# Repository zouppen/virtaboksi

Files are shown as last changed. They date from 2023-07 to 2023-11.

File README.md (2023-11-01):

# Virtaboksi

Virtaboksi is a multi-purpose 3-channel common-earth power switch,
rating 12–48 VDC, 20 A. It has multiple operating modes:

* **Home/away switch** supporting three individual groups and is optimized
  for solar energy off-grid applications.

* **Water pump controller** with pressure sensor input and control for
  combined submersible and pressure pump system. Additionally, a
  throw-over switching capability to drop loads while pumping.

* Generic **Modbus RTU server** (slave) with 3 solid-state "coils", 3 digital
  outputs, and 4 digital inputs.

3D model

In the picture above the Powerpole connector colors are incorrect. Red
is used for inputs and black for outputs. In a real product, the three
groups have different colors: red, yellow and blue.

## Design principles

* **Flexible voltage** options; 10–34 V input on first group, 10–60 V on
  second and third group.
* **High current** support. With passive cooling, 20 A loads can be
  controlled. MOSFETs are capable of switching over 100 A continuous
  current in case where cooling and PCB traces are reinforced.
* **Small** size: Thanks to transistor control, the size is way smaller than for
  three contactors of similar rating.
* **Low losses**: Internal resistance <10mΩ.
* **Rugged**: All digital I/O ports are short-circuit, reverse voltage and
  surge protected.
* **Power saving**: When loads are off, the power consumption is minimal,
  less than 5mW, allowing it to be left powered on over dark winters.
* **Hacker friendly**: You can create your own firmware for the STM8
  microcontroller, allowing real-time and stand-alone control of your
  loads and connectivity to other peripherals up to **1 km** distance
  over RS-485.

## Operating modes

### Home/away mode

Status: 💚 **Functional**

This unit provides *priority* output on OUT1 when the switch is in
either *home* or *away* position. *Home* controls OUT2 and OUT3 groups
and can be used to control two separate voltages as long as they have
a common ground.

An example use case is a solar off-grid system with two 12V batteries
in series providing 24 volts, plus 12 volts generated from 24V using a
step-down DC converter. DC converter is not included in the package.

In that case this switch can be used to turn the loads partially while
being away, such as keeping refrigerator running but turning off
lights while not present. When using a DC converter, its input is connected
OUT1 its output (12V) to IN3.

Maximum voltage in IN1 is 34 VDC. The limitation comes from the
internal power supply. In case you want to use higher voltages in IN1,
cut the trace F1 on the bottom of this board and power the system
directly from a regulated 3.3 VDC supply via the terminals.

IN2 and IN3 are rated for 60 volts maximum, making it possible to
control 48V nominal voltage loads. Minimum voltage for all groups is
about 10 volts. Under 10 volts, MOSFET control becomes unreliable.

#### How to connect

In home/away mode, when I1 is shorted to the ground, the oprating mode
is *away*. When I2 is shorted, the mode is *home*. If both connectors
are open, operating mode is *off*.

Optionally, LED anodes can be connected directly to O1 and O2. They
represent home and away operating modes, in that order. There is a
current limiter controllable by R1 to limit the maximum current of
O1...O3 to about 15 mA by default, so series resistors are not needed.

If your solar controller has a low battery condition relay, it can be
connected to I3. When the input is high, the system is forced to off mode,
ignoring the state of home/away switch.

I4 is not used in this mode.

### Water pump controller mode

Status: 🔬 **Hardware OK**

Hardware is capable, but no firmware support yet.

### Modbus RTU server mode

Status: 🔬 **Hardware OK**

RS-485 hardware is tested and some firmware tests performed, but no
Modbus implementation exists yet.

## Building firmware

To build firmware, you need CMake and sdcc. The preparations are very
standard CMake stuff. In `firmware` subdirectory, run:

```sh
mkdir build
cd build
cmake ..
```

And then, `make` compiles it. Alternatively, `make upload` to compile
and flash.

## License

The firmware is free software: you can redistribute it and/or modify
it under the terms of the GNU Affero General Public License as
published by the Free Software Foundation, either version 3 of the
License, or (at your option) any later version.

The hardware is provided as source-available: The schematics and PCB
layout are provided for reference only. The files can be freely
distributed without limitations but no derivative works are allowed
without a permission from the copyright holders.

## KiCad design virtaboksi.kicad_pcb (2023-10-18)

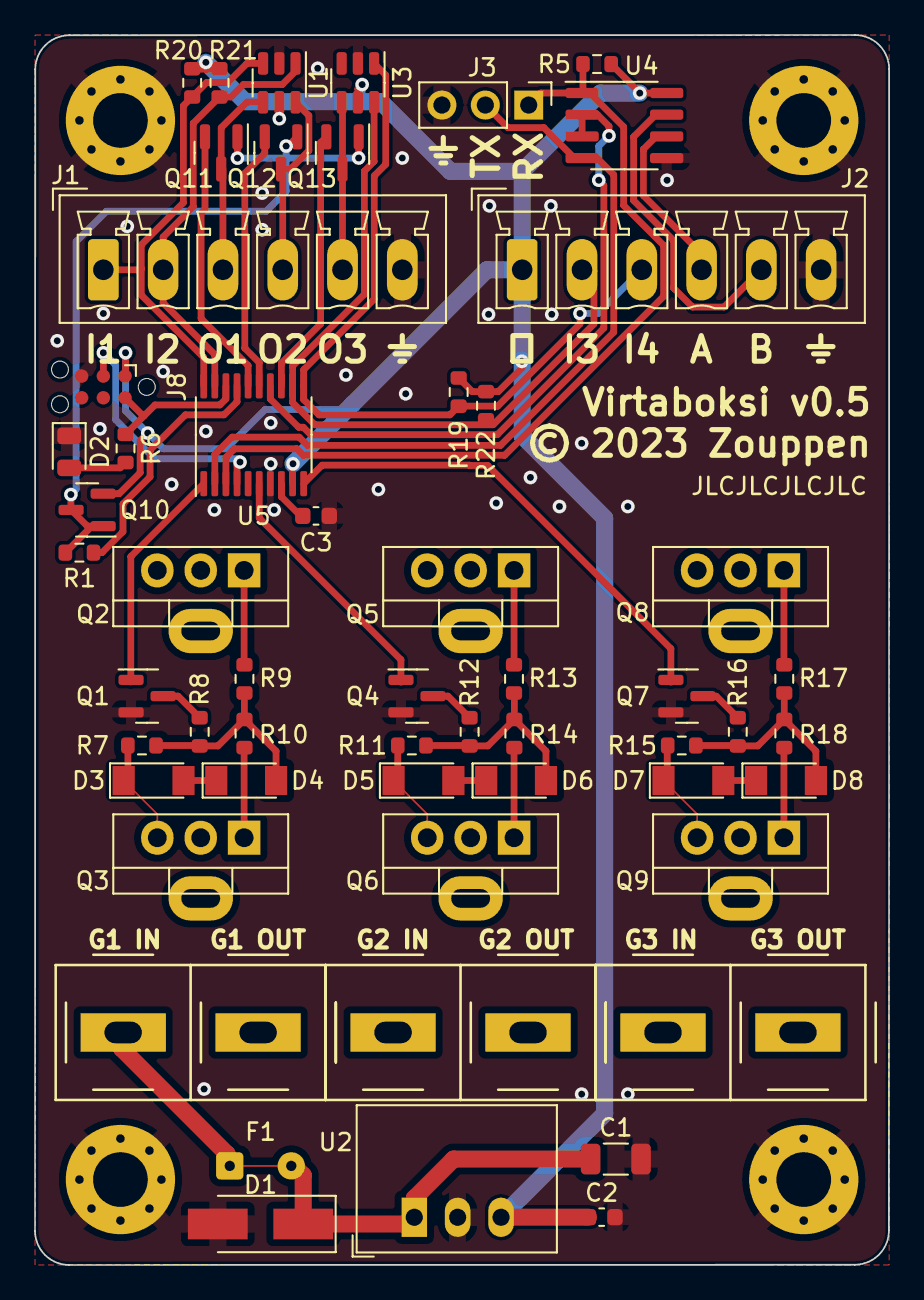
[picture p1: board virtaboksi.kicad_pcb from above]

Board: 2 copper layers, 50.0 x 72.0 mm, 66 parts (0 on the bottom side), 48 nets.

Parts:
C1: 10u; C_1206_3216Metric
C2: 22u; C_0603_1608Metric
C3: 1u; C_0603_1608Metric
D1: SMAJ33A; D_SMA_Handsoldering
D2: LED; LED_0805_2012Metric
D3, D4, D5, D6, D7, D8: ZMM5V6-M; D_MiniMELF
F1: Fuse; Fuse-kindof_1x02_P3.6mm_D0.4mm_OD1mm
H1, H2, H3, H4: MountingHole_Pad; MountingHole_3.2mm_M3_Pad_Via
HS1, HS2, HS3, HS4, HS5, HS6: Heatsink; Heatsink_AAVID_576802B03900G-nocourt
J1: Panel_01x06; PhoenixContact_MCV_1,5_6-G-3.5_1x06_P3.50mm_Vertical
J2: External_01x06; PhoenixContact_MCV_1,5_6-G-3.5_1x06_P3.50mm_Vertical
J3: Optional_01x03; PinHeader_1x03_P2.54mm_Vertical
J5, J6, J7: Powerpole 01x02; 45A-VERT-PAIR
J8: TagConnect_TC2030-NL; Tag-Connect_TC2030-IDC-NL_2x03_P1.27mm_Vertical
Q1, Q4, Q7: 2N7002; SOT-23
Q2, Q3, Q5, Q6, Q8, Q9: IRF4905; TO-220-3_Vertical
Q10, Q11, Q12, Q13: MMBT3906; SOT-23
R1, R6: 220; R_0603_1608Metric
R5: 20k; R_0603_1608Metric
R7, R11, R15: 68k; R_0603_1608Metric
R8, R12, R16: 13k; R_0603_1608Metric
R9, R10, R13, R14, R17, R18: 10; R_0603_1608Metric
R19, R20, R21, R22: 5k; R_0603_1608Metric
U1, U3: SRV05-4; SOT-23-6
U2: AMSRI-783.3-NZ; Converter_DCDC_RECOM_R-78E-0.5_THT
U4: SP3485EN; SOIC-8_3.9x4.9mm_P1.27mm
U5: STM8S003F3P; TSSOP-20_4.4x6.5mm_P0.65mm

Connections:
+3.3V: C2.1, J2.1, J8.1 (VCC), Q10.2 (E), R5.1, R19.1, R20.1, R21.1, R22.1, U1.5 (VP), U2.3 (OUT), U3.5 (VP), U4.8 (VCC), U5.9 (VDD)
/GROUP1 CTRL: Q1.1 (G), U5.1 (PD4)
/GROUP1 IN: D3.1 (K), F1.1, J7.2, Q2.3 (S), Q3.3 (S), R7.1
/GROUP1 OUT: HS1.1, HS2.1, J7.1, Q2.2 (D), Q3.2 (D)
/GROUP2 CTRL: Q4.1 (G), U5.6 (PA2)
/GROUP2 IN: D5.1 (K), J6.2, Q5.3 (S), Q6.3 (S), R11.1
/GROUP2 OUT: HS3.1, HS4.1, J6.1, Q5.2 (D), Q6.2 (D)
/GROUP3 CTRL: Q7.1 (G), U5.10 (PA3)
/GROUP3 IN: D7.1 (K), J5.2, Q8.3 (S), Q9.3 (S), R15.1
/GROUP3 OUT: HS5.1, HS6.1, J5.1, Q8.2 (D), Q9.2 (D)
/IN1: J1.1, R20.2, U1.3 (IO2), U5.20 (PD3)
/IN2: J1.2, R21.2, U1.1 (IO1), U5.19 (PD2)
/IN3: J2.2, R22.2, U3.6 (IO4), U5.12 (PB4)
/IN4: J2.3, R19.2, U3.1 (IO1), U5.11 (PB5)
/IREF: Q10.1 (B), Q10.3 (C), Q11.1 (B), Q12.1 (B), Q13.1 (B), R1.1
/IREF_EN: R1.2, U5.17 (PC7)
/O1: J1.3, Q11.3 (C), U1.4 (IO3)
/O1uC: Q11.2 (E), U5.16 (PC6)
/O2: J1.4, Q12.3 (C), U1.6 (IO4)
/O2uC: Q12.2 (E), U5.15 (PC5)
/O3: J1.5, Q13.3 (C), U3.4 (IO3)
/O3uC: Q13.2 (E), U5.13 (PC3)
/PWR1: C1.1, D1.1 (A1), F1.2, U2.1 (IN)
/RESET: J8.3 (~RESET), U5.4 (NRST)
/RX: J3.1, R5.2, U4.1 (RO), U5.3 (PD6)
/SWIM: J8.2 (SWDIO), R6.2, U5.18 (PD1)
/TX: J3.2, U4.4 (DI), U5.2 (PD5)
/TX_EN: U4.2 (~RE), U4.3 (DE), U5.14 (PC4)
/mosfet_switch1/DRIVE: D4.2 (A), R7.2, R8.1, R9.1, R10.1
/mosfet_switch1/DRIVE_A: Q2.1 (G), R9.2
/mosfet_switch1/DRIVE_B: Q3.1 (G), R10.2
/mosfet_switch2/DRIVE: D6.2 (A), R11.2, R12.1, R13.1, R14.1
/mosfet_switch2/DRIVE_A: Q5.1 (G), R13.2
/mosfet_switch2/DRIVE_B: Q6.1 (G), R14.2
/mosfet_switch3/DRIVE: D8.2 (A), R15.2, R16.1, R17.1, R18.1
/mosfet_switch3/DRIVE_A: Q8.1 (G), R17.2
/mosfet_switch3/DRIVE_B: Q9.1 (G), R18.2
A: J2.4, U4.6 (A)
B: J2.5, U4.7 (B)
GND: C1.2, C2.2, C3.2, D1.2 (A2), D2.1 (K), H1.1, H2.1, H3.1, H4.1, J1.6, J2.6, J3.3, J8.5 (GND), Q1.2 (S), Q4.2 (S), Q7.2 (S), U1.2 (VN), U2.2 (GND), U3.2 (VN), U4.5 (GND), U5.7 (VSS)
unnamed: C3.1, U5.8 (VCAP)
unnamed: D2.2 (A), R6.1
unnamed: D3.2 (A), D4.1 (K)
unnamed: D5.2 (A), D6.1 (K)
unnamed: D7.2 (A), D8.1 (K)
unnamed: Q1.3 (D), R8.2
unnamed: Q4.3 (D), R12.2
unnamed: Q7.3 (D), R16.2

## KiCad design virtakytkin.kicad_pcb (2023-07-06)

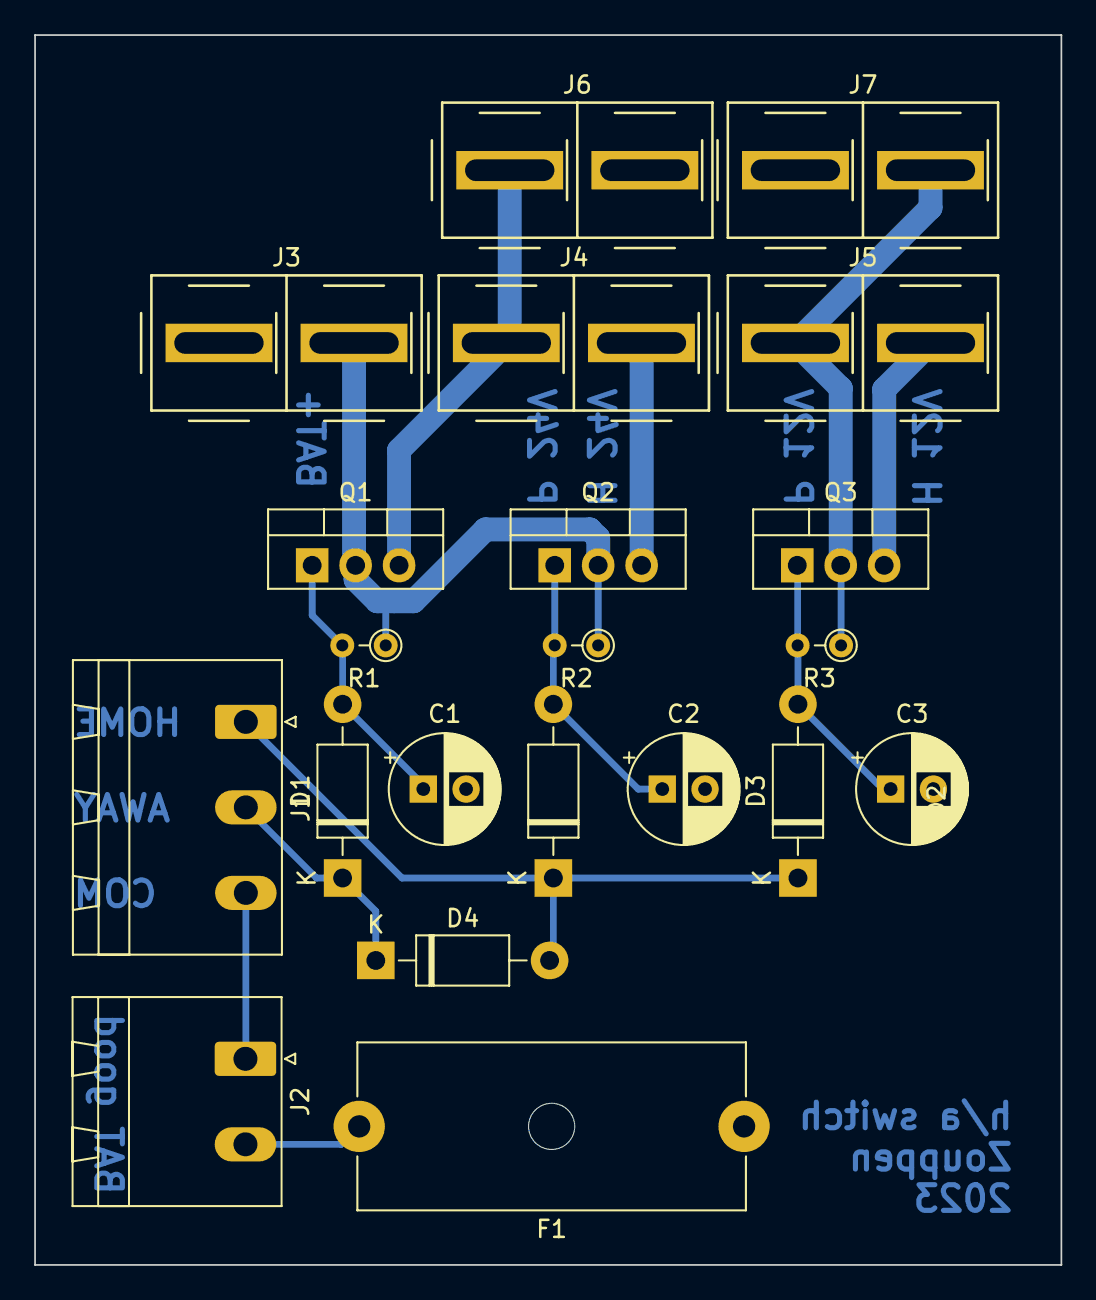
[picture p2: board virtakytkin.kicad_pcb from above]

Board: 2 copper layers, 60.0 x 71.9 mm, 21 parts (0 on the bottom side), 13 nets.

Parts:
C1, C2, C3: C_Polarized; CP_Radial_D6.3mm_P2.50mm
D1, D2, D3, D4: 1N4001; D_DO-41_SOD81_P10.16mm_Horizontal
F1: Fuse; Fuseholder_Cylinder-5x20mm_Schurter_0031_8201_Horizontal_Op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
J1: Conn_01x03_Female; PhoenixContact_MSTBA_2,5_3-G_1x03_P5.00mm_Horizontal
J2: Conn_01x02_Female; PhoenixContact_MSTBA_2,5_2-G_1x02_P5.00mm_Horizontal
J3, J4, J5, J6, J7: Conn_01x02_Female; 45A-VERT-PAIR
Q1, Q2, Q3: IRF9540N; TO-220-3_Vertical
R1, R2, R3: 100k; R_Axial_DIN0204_L3.6mm_D1.6mm_P2.54mm_Vertical

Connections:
+BATT: J3.2, Q1.2 (D), Q2.2 (D), R1.1, R2.1
/AWAY: D1.1 (K), D4.1 (K), J1.2
/BAT GOOD: J1.3, J2.1
/HOME: D2.1 (K), D3.1 (K), D4.2 (A), J1.1
/HOME 12V: J5.2, Q3.3 (S)
/HOME 24V: J4.2, Q2.3 (S)
/PRI 12V: J5.1, J7.2, Q3.2 (D), R3.1
/PRI 24V: J4.1, J6.1, Q1.3 (S)
GND: C1.2, C2.2, C3.2, F1.1, J3.1, J6.2, J7.1
unnamed: C1.1, D1.2 (A), Q1.1 (G), R1.2
unnamed: C2.1, D2.2 (A), Q2.1 (G), R2.2
unnamed: C3.1, D3.2 (A), Q3.1 (G), R3.2
unnamed: F1.2, J2.2

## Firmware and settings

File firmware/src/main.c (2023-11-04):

/* Firmware for Virtaboksi v0.4 and above */
#include <stm8.h>
#include <string.h>
#include "board.h"
#include "iref.h"
#include "util.h"
#include "serial.h"
#include "timers.h"
#include "settings.h"

#define HALT_ENABLED

// On bootup, have a small pause after bootup before switching loads,
// to avoid oscillation in case of a boot loop.
static uint16_t ctrl_debounce = STARTUP_DEBOUNCE_TICKS;

// In case excessive flipflopping, turn all outputs off since it might
// be an indicator of a hardware error.
static uint16_t ctrl_panic = PANIC_OFF_TICKS;

// A global flag for carrying state from ISR to main loop
static volatile bool timers_running = true;

static void controlled_halt(void);
static void update_outputs_IM(bool const panic);
static void debounce_arm_IM(void);
static bool debounce_tick_IM(void);
static void setup_IM(void);
static void loop(void);

// Halts CPU. This must be called outside of interrupt handlers but
// interrupts disabled. Like wfi(), enables interrupts on return.
static void controlled_halt(void)
{
	// "Unreal mode" for serial traffic. Enable interrupt for the
	// serial pin and it magically wakes up after serial activity,
	// although this shouldn't be possible according to STM8S data
	// sheet (rx can't emit an interrupt while in HALT mode.
	REG_HIGH(CR2, PIN_RX);

	// Turn off the running indicator
	LOW(PIN_LED_PCB);

	// We may wake up because of start bit on UART line, meaning
	// the first byte hasn't been yet received. Ensuring that
	// we'll stay awake until the end of first byte at minimum.
	timers_stay_awake_IM(MINIMUM_WAKEUP_TICKS);
	timers_running = true;

	// Put IREF to powersave if no LEDs are lit
	iref_maybe_off_IM();

	halt();

	// WAKE UP!! Rise and shine! Interrupts are automatically
	// enabled on wake-up, so suppressing them again. In case of
	// serial traffic, int_on_portd() has been already called
	// before getting here because it's impossible to wake up
	// without going to interrupt handlers.
	__critical {
		// Suppress future spurious calls to int_on_portd()
		REG_LOW(CR2, PIN_RX);

		// Put IREF on while we stay awake
		iref_on_IM();
	}
}

static void update_outputs_IM(bool const panic)
{
	bool const sw_away = !READ(PIN_IN1);
	bool const sw_home = !READ(PIN_IN2);
	bool const bat_good = READ(PIN_IN3);
	bool const sw_main = sw_home || sw_away;

	if (panic || !bat_good || !sw_main) {
		// BAT bad or OFF state: all outputs off
		LOW(PIN_GROUP1);
		LOW(PIN_GROUP2);
		LOW(PIN_GROUP3);
		// Indicator LEDs
		LOW(PIN_OUT1);
		LOW(PIN_OUT2);
	} else if (sw_home) {
		// Home: All outputs on
		HIGH(PIN_GROUP1);
		HIGH(PIN_GROUP2);
		HIGH(PIN_GROUP3);
		// Indicator LEDs
		LOW(PIN_OUT1);
		HIGH(PIN_OUT2);
	} else {
		// Away: PRI on
		HIGH(PIN_GROUP1);
		LOW(PIN_GROUP2);
		LOW(PIN_GROUP3);
		// Indicator LEDs
	        HIGH(PIN_OUT1);
		LOW(PIN_OUT2);
	}
}

static void debounce_arm_IM(void)
{
	ctrl_debounce = DEBOUNCE_TICKS;
}

static bool debounce_tick_IM(void)
{
	if (ctrl_debounce) {
		if (--ctrl_debounce) {
			// Still running
			if (ctrl_panic && !--ctrl_panic) {
				// Running for too long
				update_outputs_IM(true);
			}
			return true;
		}
		// Reached zero
		ctrl_panic = PANIC_OFF_TICKS;
		update_outputs_IM(false);
	}
	return false;
}

void int_on_portb(void) __interrupt(EXTI1_ISR)
{
	debounce_arm_IM();
}

void int_on_portc(void) __interrupt(EXTI2_ISR)
{
	debounce_arm_IM();
}

void int_on_portd(void) __interrupt(EXTI3_ISR)
{
	// OBS! When we wake up from serial activity, we get here once
	// and it's inevitable.
}

void run_every_1ms(void) __interrupt(TIM2_OVF_ISR)
{
	// Clear Timer 2 Status Register 1 Update Interrupt Flag (UIF)
	TIM2_SR1 &= ~TIM_SR1_UIF;

	// Blink the LED when in operation
	TOGGLE(PIN_LED_PCB);

	// Process ticks
	bool const debouncing = debounce_tick_IM();
	bool const ticking = timers_tick_IM();
	serial_tick_IM();

	// Update the global flag to indicate readiness for a sleep.
	timers_running = debouncing || ticking;
}

int main(void)
{
	// Configure device and enable interrupts.
	setup_IM();
	enable_interrupts();

	// Stay in light sleep to keep timers going. If nothing to
	// run, go to halt mode.
	while (true) {
		loop();

		// Block interrupts while whe figure out sleep method.
		disable_interrupts();

		// If there are still messages to process, go to loop.
		if (serial_has_message_IM()) {
			enable_interrupts();
			continue;
		}
#ifdef HALT_ENABLED
		if (!timers_running && !serial_is_transmitting()) {
			controlled_halt();
		} else {
			wfi();
		}
#else
		wfi();
#endif
		// Both controlled_halt() and wfi() implicitly enable
		// interrupts.
	}
}

static void setup_IM(void)
{
	// Setting clock speed
	stm8_configure_clock();

	settings_init();

	// As suggested in chapter 11.5 of RM0016, unused pins are set
	// to pull-up state. We make them all pull-up first, it's safe.
	PA_CR1 = 0xFF;
	PB_CR1 = 0xFF;
	PC_CR1 = 0xFF;
	PD_CR1 = 0xFF;
	PE_CR1 = 0xFF;
	PF_CR1 = 0xFF;

	// LED is push-pull output (CR1 already set)
	OUTPUT(PIN_LED_PCB);

	// Inputs have already discrete pull-up resistors, so we turn
	// their pull-up off (CR1) and enable interrupts (CR2).
	REG_LOW(CR1, PIN_IN1);
	REG_LOW(CR1, PIN_IN2);
	REG_LOW(CR1, PIN_IN3);
	REG_LOW(CR1, PIN_IN4);
	REG_HIGH(CR2, PIN_IN1);
	REG_HIGH(CR2, PIN_IN2);
	REG_HIGH(CR2, PIN_IN3);
	REG_HIGH(CR2, PIN_IN4);

	// Serial port has an external pull-up, too, disabling pull-up
	REG_LOW(CR1, PIN_RX);

	// MOSFET controls and LEDs are push-pull outputs
	// (CR1 already set)
	OUTPUT(PIN_GROUP1);
	OUTPUT(PIN_GROUP2);
	OUTPUT(PIN_GROUP3);
	OUTPUT(PIN_OUT1);
	OUTPUT(PIN_OUT2);
	OUTPUT(PIN_OUT3);

	// Must be on before LEDs are controlled
	BOARD_IREF_CONF;
	iref_on_IM();

	// Make interrupts trigger on both edges
	EXTI_CR1 = 0xff;

	// Timer prescale to 125 kHz
	TIM2_PSCR = TICK_PRESCALE;
	// Counter Auto-Reload Registers, the main tick timer
	TIM2_ARRH = TICK_USEC >> 8;
	TIM2_ARRL = TICK_USEC & 0xff;
	// Interrupt Enable Register, Update interrupt (UIE)
	TIM2_IER = TIM_IER_UIE;
	// Control Register 1, Counter ENable bit (CEN)
	TIM2_CR1 = TIM_CR1_CEN;

	serial_init();
}

// Run after waking up from the interrupts. Can be used to
// perform longer duration tasks. Interrupts are enabled.
static void loop(void)
{
	serial_buffer_t *const rx = serial_get_message();
	if (rx == NULL) return;

	if (rx->state == TEXT) {
		if (!strcmp(rx->data, "PAUSES")) {
			strcpy(serial_tx, "taukoja ei ole");
		} else {
			// We've got a line, let's convert it. This is a
			// little bit unsafe, but is a placeholder for the
			// real logic only.
			strcpy(serial_tx, "Saatiin: ");
			buflen_t const head = 9;
			for (buflen_t i=0; i<SERIAL_TX_LEN-head; i++) {
				char const c = rx->data[i];
				if (c == '\0') {
					serial_tx[head+i] = '\0';
					break;
				} else {
					serial_tx[head+i] = util_rot13(c);
				}
			}
		}
		serial_tx_line();
	} else {
		// We don't understand this message type (yet)
	}

	serial_free_message();
}

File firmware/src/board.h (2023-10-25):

#pragma once

#if defined BOARD_0_4
// Board version 0.4 configuration
#define PIN_IN1       PC,7
#define PIN_IN2       PC,6
#define PIN_IN3       PC,5
#define PIN_IN4       PC,4
#define PIN_GROUP1    PD,4
#define PIN_GROUP2    PA,3
#define PIN_GROUP3    PA,2
#define PIN_OUT1      PB,4
#define PIN_OUT2      PB,5
#define PIN_OUT3      PC,3
#define PIN_LED_PCB   PD,1
#define PIN_TX_EN     PD,2,3

// IREF is not present on this board
#define BOARD_IREF_CONF
#define BOARD_IREF_ON
#define BOARD_IREF_OFF

#elif defined BOARD_0_5
// Board version 0.5 configuration
#define PIN_IN1       PC,7
#define PIN_IN2       PC,4
#define PIN_IN3       PB,4
#define PIN_IN4       PB,5
#define PIN_GROUP1    PD,4
#define PIN_GROUP2    PA,2
#define PIN_GROUP3    PA,3
#define PIN_OUT1      PC,6
#define PIN_OUT2      PC,5
#define PIN_OUT3      PC,3
#define PIN_LED_PCB   PD,1
#define PIN_TX_EN     PD,2

// IREF is not present on this board
#define BOARD_IREF_CONF  OUTPUT(PD,3)
#define BOARD_IREF_ON    HIGH(PD,3)
#define BOARD_IREF_OFF   LOW(PD,3)

#else
#error Unknown board version.
#endif

// Constant pins for STM8S003
#define PIN_RX        PD,6

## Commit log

2023-07-06 Add current version of the project
    [virtakytkin.kicad_pcb, virtakytkin.kicad_sch]
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2023-07-06 Move powerpoles so that they are stackable
    [virtaboksi.kicad_pcb]
2023-07-06 Fine-tuning of the board
    [virtaboksi.kicad_pcb, virtaboksi.kicad_sch]
2023-07-06 Finetuning layout & adding TVS diode
    [virtaboksi.kicad_pcb, virtaboksi.kicad_sch]
2023-07-17 MOSFET drain and source were flipped
    [virtaboksi.kicad_pcb, virtaboksi.kicad_sch]
2023-07-17 Run the thing in Falstad's simulator and adjust the circuit
    [virtaboksi.kicad_pcb, virtaboksi.kicad_sch]
2023-07-18 Change caps from elco to ceramic, reannotate
    [virtaboksi.kicad_pcb, virtaboksi.kicad_sch]
2023-07-18 Move overvoltage protection diode down, center DC converter pins
    [virtaboksi.kicad_pcb]
2023-07-18 Remove grounding pins for DC converter
    [virtaboksi.kicad_pcb, virtaboksi.kicad_sch]
2023-07-18 Move back copper labels to a more logical position
    [virtaboksi.kicad_pcb]
2023-07-18 Add gerber export directory
    [virtaboksi.kicad_pcb]
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2023-07-22 Make schematics more readable, no functional changes
    [virtaboksi.kicad_pcb, virtaboksi.kicad_sch]
2023-07-28 Add origin point to the PCB
    [virtaboksi.kicad_pcb]
2023-07-29 Double FET 2-layer design with JLCPCB annotations
    [virtaboksi.kicad_pcb, virtaboksi.kicad_sch]
2023-07-29 Get rid of warnings, make TagConnect region more beautiful
    [virtaboksi.kicad_pcb, virtaboksi.kicad_sch]
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2023-07-29 Update PCB labels to more understandable ones
    [virtaboksi.kicad_pcb]
2023-07-29 Add more capacitance to DC converter output, add DC output pins, minor cleanup
    [virtaboksi.kicad_pcb, virtaboksi.kicad_sch]
2023-07-29 Make voltage planes larger and remove solder mask from there
    [virtaboksi.kicad_pcb]
2023-07-29 Change TVS diode type to 33.3V
    This is to avoid TVS breakdown during solar charge controller
    equalization charge which uses higher voltages (up to 32 volts). The
    regulator type is updated to the one we plan to use (36V version).
    [virtaboksi.kicad_pcb, virtaboksi.kicad_sch]
2023-07-29 Fine tune solder mask hole
    [virtaboksi.kicad_pcb]
2023-07-30 Heavily refactor board layout
    [virtaboksi.kicad_pcb, virtaboksi.kicad_sch]
2023-07-30 Make it pass DRC
    [virtaboksi.kicad_pcb]
2023-07-30 Making some small changes to improve ground connections
    [virtaboksi.kicad_pcb]
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2023-07-30 Fixes suggested by DRC
    [virtaboksi.kicad_pcb]
2023-07-30 Small improvements
    - Add extra single pin for debugging microcontroller code
    - Add vias to screw holes
    [virtaboksi.kicad_pcb, virtaboksi.kicad_sch]
2023-07-30 Enlarge thermal reliefs and remove them for some pins
    [virtaboksi.kicad_pcb]
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2023-08-16 Finished version 0.3, ready for prototype production
    [virtaboksi.kicad_pcb, virtaboksi.kicad_sch]
2023-08-16 Fix indent and comments. Make volatile var volatile
    [main.c]
2023-08-16 Fix old labels on the silkscreen
    [virtaboksi.kicad_pcb]
2023-08-17 Updated connectors, causing large diff of nothing
    [virtaboksi.kicad_pcb]
2023-09-05 Invert SW_BAT to be NC instead of NO. Reduce debounce to 100ms.
    [virtaboksi.kicad_pcb]
2023-09-17 Update transistor numbers in schematic text
    [virtaboksi.kicad_sch]
2023-09-17 Group heatsinks to one place on the schematics
    [virtaboksi.kicad_sch]
2023-09-17 Rename pri, home, etc. as group1,2,3
    [virtaboksi.kicad_sch]
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2023-09-25 Add 2.54mm pin header for RX/TX to ease debugging
    [virtaboksi.kicad_pcb, virtaboksi.kicad_sch]
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2023-09-26 Update solder mask, do final tweaks, make it pass ERC & DRC
    [virtaboksi.kicad_pcb, virtaboksi.kicad_sch]
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2023-09-27 Throw fuse out of the window, clear space left of J2, add 2 extra pins
    [virtaboksi.kicad_pcb, virtaboksi.kicad_sch]
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2023-09-28 Move one input to external connector, make them same length
    [virtaboksi.kicad_pcb, virtaboksi.kicad_sch]
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2023-10-05 Remove extra E1 and E2 labels, that connector is removed already
    [virtaboksi.kicad_pcb]
2023-10-05 Flip TX_EN1 and TX_EN2, reroute PCB a bit
    [virtaboksi.kicad_pcb, virtaboksi.kicad_sch]
2023-10-06 Adjust component and trace placement to make screw positions nice
    [virtaboksi.kicad_pcb]
2023-10-06 Move TC2030 connector so that it's not blocked by heat shield
    [virtaboksi.kicad_pcb]
2023-10-06 Swap J1 and J2 and move vias a little
    [virtaboksi.kicad_pcb, virtaboksi.kicad_sch]
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2023-10-07 Final tweaks to the PCB. Swap LED pins for better routing.
    [virtaboksi.kicad_pcb, virtaboksi.kicad_sch]
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2023-10-09 Move SMD LED so that it's not blocked by a heat sink
    [virtaboksi.kicad_pcb]
2023-10-10 Evacuate output from PA1, not working with halt mode
    [virtaboksi.kicad_pcb, virtaboksi.kicad_sch]
2023-10-11 Reverse LED logic to drive low and switch pins to match my test hardware
    [main.c]
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2023-10-12 Approach version 0.5. Let it cool down for day or two.
    [mosfet.kicad_sch, virtaboksi.kicad_pcb, virtaboksi.kicad_sch]
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2023-10-12 Switch to 220 ohm resistor to generate 15 mA
    [virtaboksi.kicad_pcb, virtaboksi.kicad_sch]
2023-10-12 Move labels, change on-board LED resistor from 180 ohm to 220
    [virtaboksi.kicad_pcb, virtaboksi.kicad_sch]
2023-10-12 Move AIN4 pin to IN2 to make it possible to use it for analog in the future
    [virtaboksi.kicad_pcb, virtaboksi.kicad_sch]
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2023-10-12 Small tweaks such as renaming OxINT to OxuC
    Old name confused because INT is often interrupt
    [virtaboksi.kicad_pcb, virtaboksi.kicad_sch]
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2023-10-13 Incorrect part number spotted before production, 1.5kohm -> 4.7kohm
    [virtaboksi.kicad_pcb, virtaboksi.kicad_sch]
2023-10-13 Make clearance larger for power lines and relief smaller for ground (both now 0.4mm)
    [virtaboksi.kicad_pcb, virtaboksi.kicad_sch]
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2023-10-13 Move capacitors so that traces make up direct lines
    [virtaboksi.kicad_pcb]
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2023-10-13 Add JLCPCB order number to a predefined spot
    [virtaboksi.kicad_pcb]
2023-10-13 Rename IN1..3 as Gn IN and OUT1..3 Gn OUT on silkscreen
    [virtaboksi.kicad_pcb]
2023-10-14 Reorganize pins so that we got two analog inputs, bot I1 and I2
    [virtaboksi.kicad_pcb, virtaboksi.kicad_sch]
2023-10-14 Mosfet drive clearances larger, update comments
    [mosfet.kicad_sch, virtaboksi.kicad_pcb, virtaboksi.kicad_sch]
2023-10-14 Minor tweak: reset trace routing
    [virtaboksi.kicad_pcb]
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2023-10-16 Fix pins to match HW version 0.4
    [main.c]
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2023-10-16 Fix interrupt number and rename debounce_check better
    [main.c, stm8.h]
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2023-10-17 Round baud rate to nearest integer, making bit error smaller
    [main.c]
2023-10-17 Make current limiter a bit more safe by making reference current sinking
    [virtaboksi.kicad_pcb, virtaboksi.kicad_sch]
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2023-10-18 Move UART header labels to the front silkscreen
    [virtaboksi.kicad_pcb]
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2023-10-18 Safety snooze suppression in serial tx is no longer needed. Works without.
    [main.c]
2023-10-18 Revert "Safety snooze suppression in serial tx is no longer needed. Works without."
    This reverts commit 3e3c97fd1bcd279d48317538d23e1e875dcc1a5b.
    [main.c]
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2023-10-19 Handle error where no board version is defined
    [board.h]
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2023-10-21 Support new -R flag in stm8flash to reset the board after flashing
    The feature is added by
    https://github.com/vdudouyt/stm8flash/pull/168
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2023-10-25 Add missing interrupt numbers for IO banks
    [stm8.h]
2023-10-25 Fix IN3 and IN4 malfunction, interrupt was missing
    [main.c]
2023-10-26 Add serial tx double buffering. WIP, it is broken.
    [main.c, serial.c]
2023-10-29 Fix serial rx problem when BREAK occurs
    It was transmitting while receiving, which breaks half-duplex.
    [main.c, serial.c]
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2023-10-30 Use the same interrupt names than lujji
    Throwing jukkas' names out of the window and replace with better ones
    from here:
    https://github.com/lujji/stm8-bare-min/blob/master/stm8s/lib/stm8s.h
    [main.c, serial.c, stm8.h]
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2023-11-01 Use settings in serial.c to avoid passing baud rate from main.c
    [main.c, serial.c]
2023-11-01 Cache modbus_silence. Otherwise takes too much time to calculate it
    [serial.c]
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
